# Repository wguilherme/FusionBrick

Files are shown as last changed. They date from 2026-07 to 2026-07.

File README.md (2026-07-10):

<div align="center">

🌐 **Português** | [English](README.en.md)

# FusionBrick

**Sistema de design modular open-source para makers, engenheiros e entusiastas.**





</div>

---

FusionBrick é um sistema de componentes modulares paramétricos para impressão 3D. Qualquer componente conecta em qualquer outro — em qualquer face, em qualquer direção — via press-fit, sem ferramentas.

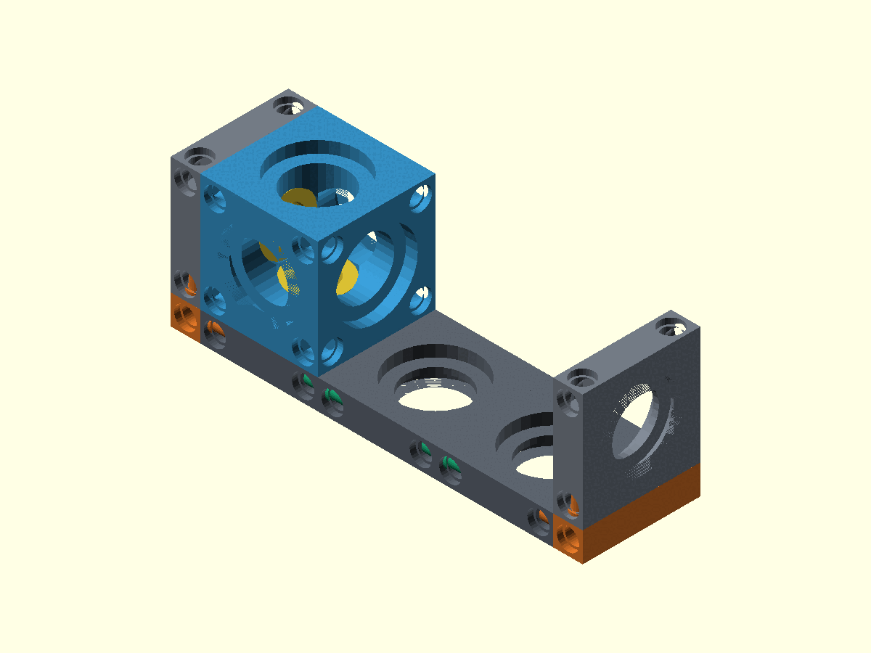
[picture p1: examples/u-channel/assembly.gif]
Montagem em U — 3 PLATEs unidas por BRIDGEs, paredes travadas por CORNERs e ATOM conectado por LINKs


---

## Componentes

| Componente | Preview | Função | Fonte |
| --- | :---: | --- | --- |
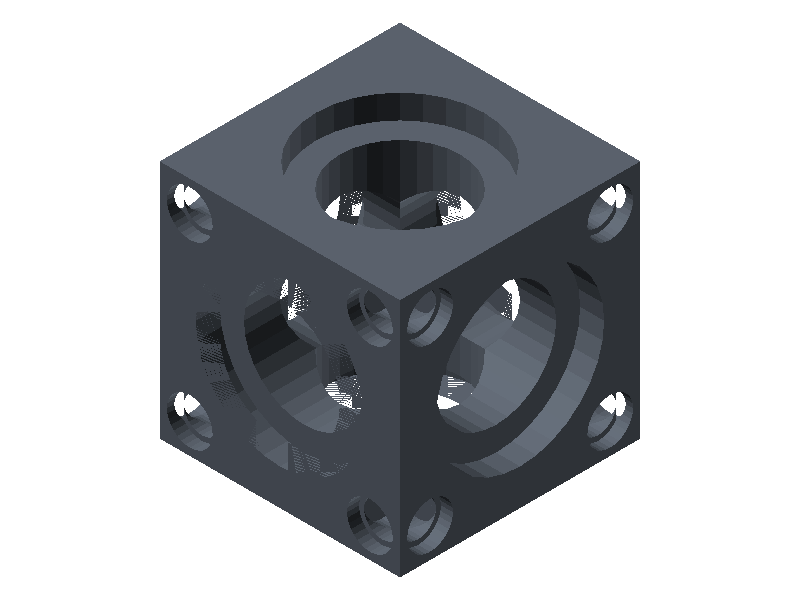
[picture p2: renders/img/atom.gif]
ATOM
| **ATOM** |  | Unidade cúbica. Furos passantes em 6 faces. | `impl/openscad/atom.scad` |
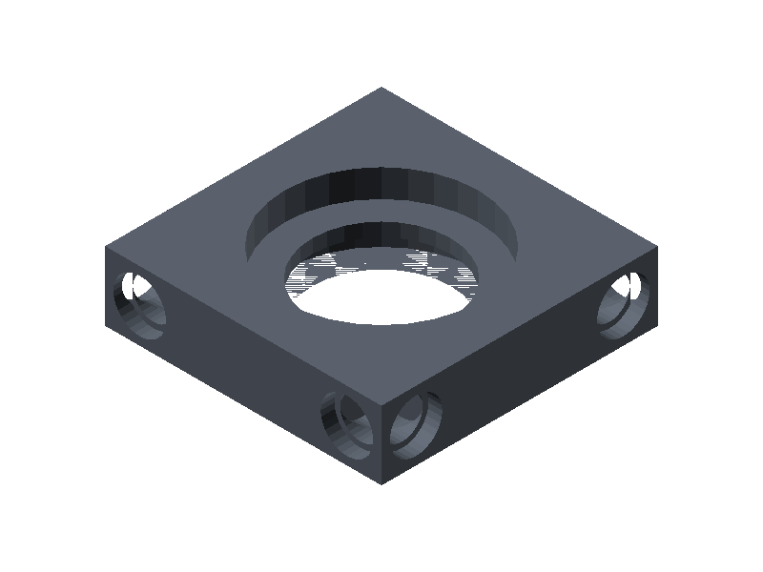
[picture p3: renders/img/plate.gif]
PLATE
| **PLATE** |  | Superfície plana. Furos alinhados ao ATOM. | `impl/openscad/plate.scad` |
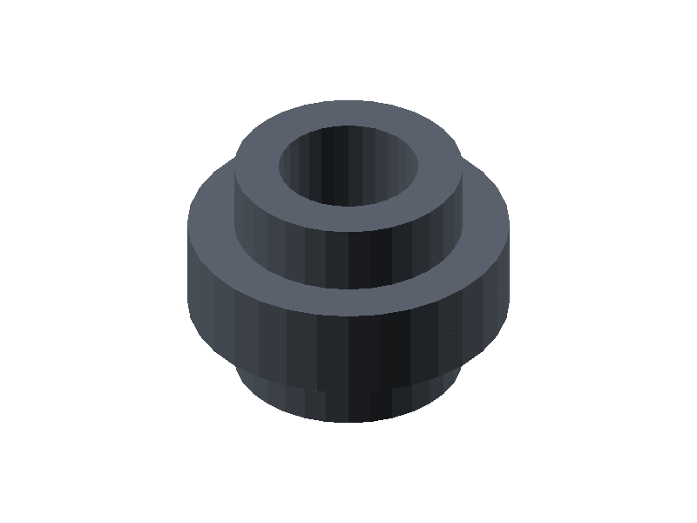
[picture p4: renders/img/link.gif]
LINK
| **LINK** |  | Conector universal entre quaisquer dois furos. | `impl/openscad/link.scad` |
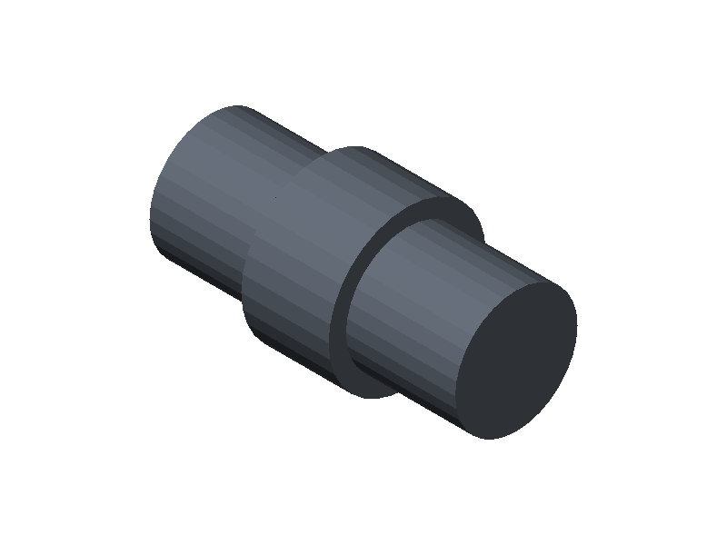
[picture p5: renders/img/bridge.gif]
BRIDGE
| **BRIDGE** |  | Dowel de junção coplanar invisível (PLATE↔PLATE, PLATE↔ATOM). | `impl/openscad/bridge.scad` |
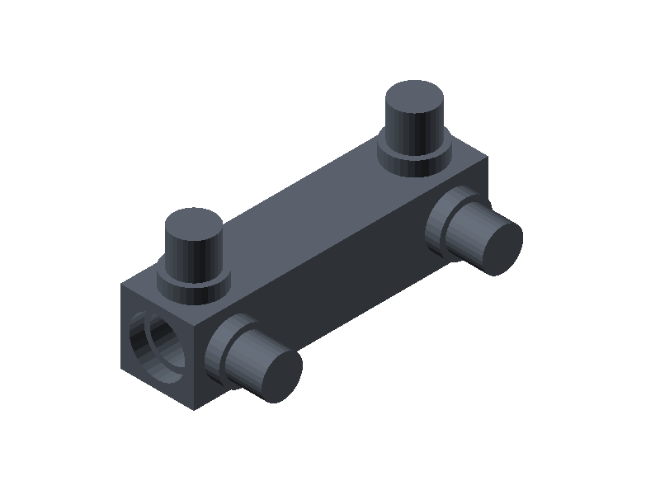
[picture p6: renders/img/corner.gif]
CORNER
| **CORNER** |  | Viga de canto. Une duas PLATEs a 90° via furos de borda. | `impl/openscad/corner.scad` |
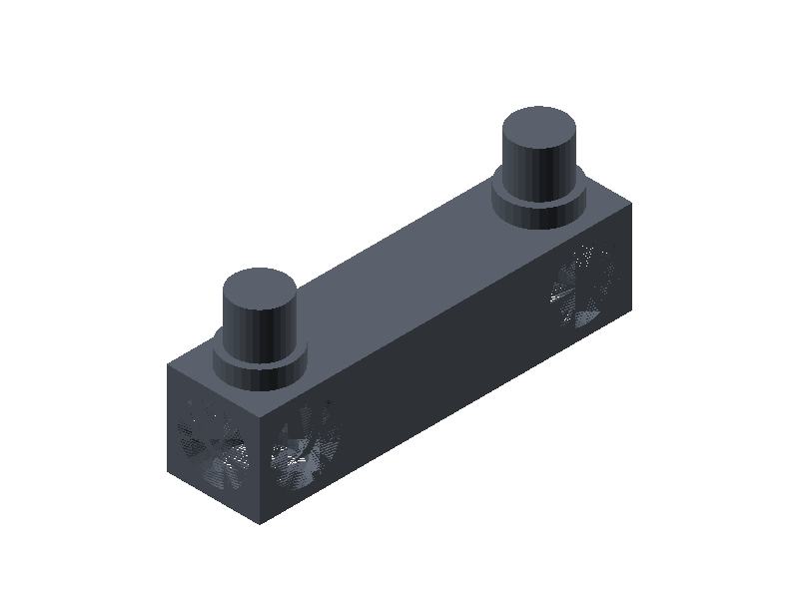
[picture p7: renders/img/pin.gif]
PIN
| **PIN** |  | Viga conectora configurável: pino, furo ou nada em cada face. Com presets. | `impl/openscad/pin.scad` |
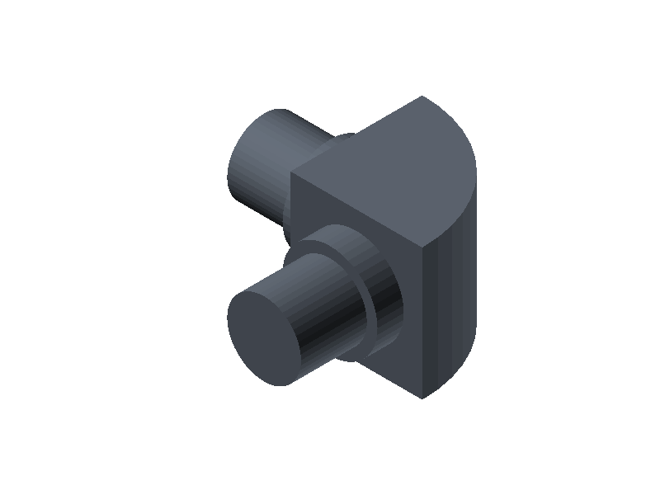
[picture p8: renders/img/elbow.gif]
ELBOW
| **ELBOW** |  | Curva 90° com canto externo arredondado. Fio vira a esquina por dentro. | `impl/openscad/elbow.scad` |
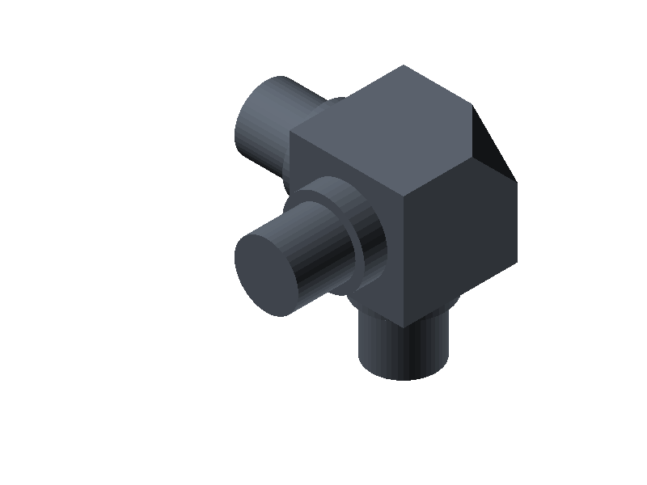
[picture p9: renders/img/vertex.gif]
VERTEX
| **VERTEX** |  | Quina 3-vias com ponta arredondada. Une base + 2 paredes num vértice. | `impl/openscad/vertex.scad` |

---

## Parâmetros Globais

Todos os parâmetros abaixo devem ser iguais entre os componentes para garantir compatibilidade.

```
cell_size     = 20mm   // unidade base da grade
hole_d        = 10mm   // diâmetro do furo
relief_depth  = 2mm    // profundidade do rebaixo
relief_margin = 2mm    // margem do rebaixo
tolerance     = 0.2mm  // tolerância de impressão (ajuste por impressora)
canal_d       = 6mm    // canal para fios em todo conector (0 = fechado)
```

Premissas do sistema: [spec/design-system.md](spec/design-system.md) · Lei do Grid e junções: [spec/rules.md](spec/rules.md).

---

## Início Rápido

**Requisitos:** OpenSCAD 2021+, impressora FDM, PLA ou PETG.

### 1. Instalar OpenSCAD

Via [download direto](https://openscad.org/downloads.html) ou via asdf:

```bash
asdf plugin add openscad https://github.com/gabrielelana/asdf-openscad
asdf install  # lê a versão de .tool-versions (2021.01)
```

### 2. Clonar e abrir

```bash
git clone https://github.com/wguilherme/FusionBrick.git
cd FusionBrick
open impl/openscad/atom.scad
```

Dentro do OpenSCAD: ajuste os parâmetros no painel lateral (ex: `atom_size`, `hole_d`, `border_radius`) → `F6` para renderizar → `File → Export → Export as STL`.

### 3. Gerar previews e STLs via Make

```bash
make preview            # renders/img/*.png — imagem isométrica de cada componente
make preview-animated   # renders/img/*.gif — giro 360° de cada componente
make build              # renders/stl/*.stl — STL pronto para fatiar
make assembly           # examples/*/assembly*.png — montagens isométricas (normal + explodida)
make assembly-animated  # examples/*/assembly.gif — giro 360° com explode/recolhe em loop
```

Para sobrescrever a cor dos componentes no preview:

```bash
make preview PART_COLOR="[0.8, 0.2, 0.1]"  # valores 0.0–1.0 (RGB)
```

Velocidade/suavidade dos GIFs animados:

```bash
make preview-animated ANIM_DELAY=10   # delay entre frames em 1/100s (padrão: 15)
make preview-animated ANIM_FRAMES=72  # frames por volta — mais suave (padrão: 36)

make assembly-animated ASM_ANIM_DELAY=10    # delay entre frames (padrão: 5)
make assembly-animated ASM_ANIM_FRAMES=96   # frames no loop completo (padrão: 72)
make assembly-animated ASM_ANIM_EXPLODE=20  # afastamento máximo em mm (padrão: 12)
make assembly-animated ASM_ANIM_SPIN=360    # habilita o giro completo (padrão: 0 — câmera isométrica fixa)
make assembly-animated ASM_ANIM_SPEED=2     # 2x mais rápido (padrão: 1; 0.5 = metade da velocidade)
```

Por padrão a câmera fica travada no ângulo isométrico (45°/54.7°) e a animação só abre/recolhe a montagem.

---

## Estrutura

```text
FusionBrick/
├── spec/                   ← especificação independente de ferramenta
│   ├── design-system.md    ← premissas do sistema
│   ├── params.md           ← parâmetros globais
│   ├── rules.md            ← Lei do Grid, interfaces, junções
│   └── parts/              ← spec de cada peça
├── impl/
│   ├── openscad/           ← implementação OpenSCAD ✅
│   ├── fusion360/          ← planejado
│   └── manual/             ← planejado
├── renders/
│   ├── img/                ← previews PNG
│   └── stl/                ← STLs exportados
└── examples/               ← montagens de exemplo (make assembly)
```

---

## Roadmap

### v0.1.0 — Fundação ✅

- [x] ATOM, PLATE, LINK
- [x] Implementação OpenSCAD
- [x] Especificação do sistema

### v0.2.0 — Junções & Interface de Borda ✅

- [x] Interface de borda: furos Ø3 nas extremidades de PLATEs e ATOMs, com rebaixo para colar
- [x] BRIDGE — dowel de junção coplanar invisível com colar central
- [x] CORNER — viga de canto 90° com canal para fio; dois CORNERs formam "L" flush
- [x] PIN — viga conectora configurável (pino/furo/nada por face) com presets
- [x] ELBOW — curva 90° arredondada; VERTEX — quina 3-vias com ponta arredondada
- [x] Canal para circuito elétrico por padrão em todo conector
- [x] Lei do Grid formalizada (`spec/design-system.md`, `spec/rules.md`)
- [x] `make assembly` — montagens isométricas com teste de colisão

### v0.3.0 — Paramétrico

- [ ] Seleção de padrão de furos (bordas, cantos, todos)
- [ ] Suporte multi-escala (10mm, 20mm, 30mm)
- [ ] Upload MakerWorld PMM

### v0.4.0+ — Futuro

- [ ] Canais para condução elétrica
- [ ] Conectores magnéticos
- [ ] Plugin Fusion 360

---

## Implementações

| Implementação | Status |
| --- | --- |
| OpenSCAD | ✅ Ativo |
| Fusion 360 | 🔜 Planejado |
| FreeCAD | 🔜 Planejado |
| MakerWorld PMM | 🔜 Planejado |

Quer contribuir? [Abra uma issue](https://github.com/wguilherme/FusionBrick/issues) ou envie um PR.

---

Feito com ❤️ para quem constrói  — [@wguilherme](https://github.com/wguilherme)

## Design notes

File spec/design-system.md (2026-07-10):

# Design System — Premissas

Princípios que governam o FusionBrick. Toda peça nova, mudança de parâmetro ou nova implementação deve respeitar todos eles. Se uma proposta viola qualquer premissa, a proposta muda — não a premissa.

## 1. O grid é sagrado

O passo do grid (`cell_size = 20mm`) nunca muda por causa de uma junção.

- Peças auxiliares (LINK, BRIDGE, CORNER e futuras) conectam furos existentes **sem inserir espaçamento**
- A espessura de PLATEs vive **fora** do volume do grid ([Lei do Grid](rules.md))
- Teste canônico: em qualquer montagem, um ATOM deve entrar em qualquer célula interior e alinhar com todos os furos vizinhos

## 2. Circuito elétrico passa por padrão

Toda peça e todo conector nascem com passagem para fio/jumper — fechar é opt-in, nunca default.

- Furos de face (`hole_d = 10mm`) são passantes
- Conectores têm canal axial: LINK `6mm`, CORNER `3mm` (mínimo: jumper Dupont, `2.5mm`)
- Quando a seção não comporta canal (ex: BRIDGE, pinos `Ø2.8`), a peça não pode bloquear as passagens existentes — a BRIDGE vive na borda justamente para deixar os furos de face livres
- `canal_d = 0` fecha o canal — escolha do usuário, nunca da spec

## 3. Compatibilidade é permanente

Tudo conecta com tudo, sempre — inclusive com peças impressas antes.

- Parâmetros globais ([params.md](params.md)) idênticos em todas as peças; divergiu, quebrou
- Peça nova deve usar as interfaces existentes ([rules.md](rules.md)); interface nova só quando nenhuma existente resolve — e vira contrato do sistema, documentada em `spec/`
- Mudança de interface é mudança de sistema: propaga para todas as peças, specs, implementações e exemplos de uma vez
- Nada de pares exclusivos: se a peça A conecta na B, deve conectar em qualquer peça com a mesma interface

## 4. Interfaces não competem

Cada interface tem seu papel; junções não consomem o recurso das outras.

| Interface | Onde | Serve para |
| --- | --- | --- |
| Face (furo `Ø10` + rebaixo `Ø14×2`) | faces de ATOM e PLATE | LINK, empilhamento, fixação de módulos |
| Borda (furo `Ø3` nas extremidades) | bordas de PLATE, faces laterais de ATOM | BRIDGE, CORNER — junções estruturais |

Consequência: montar uma junção nunca impede montar um módulo — ATOM assenta sobre qualquer junção.

## 5. Press-fit primeiro

- Sem ferramentas, sem parafusos, sem cola (cola é opção do usuário para montagem permanente)
- `tolerance = 0.2mm` subtraída sempre do conector, nunca da peça receptora — peças receptoras são nominais
- Ajuste fino por impressora acontece no conector (peça pequena, reimpressão barata)

## 6. Spec-first

- `spec/` é o contrato; `impl/` implementa. Divergência entre os dois é bug na implementação — ou proposta de mudança que deve começar pela spec
- Toda implementação (OpenSCAD, Fusion 360, …) que respeite a spec produz peças intercompatíveis

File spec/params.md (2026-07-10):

# Parâmetros Globais

Valores que devem ser idênticos em todas as peças. Se divergirem, os furos não alinham.

| Parâmetro | Valor | Descrição |
| --- | --- | --- |
| `cell_size` / `atom_size` | `20mm` | Unidade base do grid |
| `hole_d` | `10mm` | Diâmetro do furo passante |
| `relief_depth` | `2mm` | Profundidade do rebaixo |
| `relief_margin` | `2mm` | Margem do rebaixo → `relief_d = hole_d + relief_margin×2 = 14mm` |
| `tolerance` | `0.2mm` | Subtraída de pinos/flanges para press-fit |
| `canal_d` | `6mm` | Canal axial para fios em todo conector (0 = fechado) |
| `thickness` | `5mm` | Espessura padrão da PLATE — mínimo `(relief_depth×2)+1` |
| `pin_depth` | `3mm` | Profundidade do pino — caso mais restrito: PLATE (`thickness−relief_depth`) |
| `edge_hole_d` | `3mm` | Furo de borda de PLATE/ATOM (0 = desativado) |
| `edge_hole_depth` | `4mm` | Profundidade do furo de borda |
| `edge_inset` | `2.5mm` | Furo de borda a esta distância das extremidades (= `thickness/2`) |
| `edge_collar_w` | `0.4mm` | Largura radial do rebaixo/colar (= 1 bico de 0.4; 0 = desativado) |
| `edge_collar_depth` | `1mm` | Profundidade do rebaixo / altura do colar |
| `border_radius` | `0` | Acabamento das arestas externas (VERTEX: padrão `2`) |
| `border_style` | `round` | Estilo do acabamento: `round` (raio) ou `chamfer` (chanfro 45°) |
| `$fn` | `32` | Segmentos de cilindro |

## Derivados

```text
relief_d  = hole_d + relief_margin*2      = 14mm
pin_d     = hole_d - tolerance            = 9.8mm
flange_d  = relief_d - tolerance          = 13.8mm
```

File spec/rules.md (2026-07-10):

# Regras do Sistema

Regras de compatibilidade que toda peça e toda junção devem respeitar.

## Lei do Grid

> **O volume do grid é delimitado pelas faces internas das PLATEs. A espessura da PLATE vive sempre FORA do grid.**

Consequências:

1. **Superfície da base é plano do grid** — atoms assentam diretamente sobre ela; centro do atom fica a `cell_size/2` da superfície.
2. **Parede perpendicular** assenta com a borda inferior sobre a superfície da base e a face interna num plano do grid; a espessura projeta para fora.
3. **Primeiro furo de qualquer PLATE** fica a `cell_size/2` da borda → furos de parede ficam a `cell_size/2` acima da superfície da base → alinham com os furos laterais de um ATOM assentado na base.
4. Nenhuma junção pode alterar o passo do grid (`cell_size`). Peças de junção (LINK, BRIDGE, CORNER) conectam furos existentes sem inserir espaçamento.

## Junção coplanar (lado a lado)

Duas PLATEs encostadas borda a borda: furos de face ficam a `cell_size/2` de cada lado da junção → distância entre furos através da junção = `cell_size`. O grid se preserva automaticamente. Travamento **invisível** via dowels [BRIDGE](parts/bridge.md) na interface de borda (2 por junção) — faces 100% livres, ATOM assenta sobre a junção.

## Interface de borda

Segunda interface do sistema, nas bordas de PLATEs e faces laterais de ATOMs — complementa os furos de face sem competir com eles. Interface pura pino → furo, sem rebaixos:

- Furos de borda: `edge_hole_d = 3mm`, profundidade `4mm`, centrados na espessura
- 2 por célula, **nas extremidades**: a `edge_inset = 2.5mm` (= `thickness/2`) de cada limite da célula
- Distâncias: `15mm` dentro da célula; `5mm` através de junções — cada furo alinha com o centro da seção do CORNER (`5/2 = 2.5mm`)
- ATOM: 4 furos por face lateral (2 embaixo + 2 em cima), mesmas posições → PLATE ao lado de ATOM conecta direto
- **Rebaixo do colar**: boca de todo furo de borda ganha rebaixo `Ø3.8 × 1mm` (`edge_collar_w = 0.4` radial); todo pino tem colar `Ø3.6 × 1mm` na raiz → trava de profundidade (dowel divide 50/50, pino não afunda) e reforço da raiz
- Pinos receptores: `edge_hole_d - tolerance = 2.8mm`
- Usada por: [BRIDGE](parts/bridge.md) (dowel de junção coplanar), [CORNER](parts/corner.md) (junção 90° e L de corners), [PIN](parts/pin.md) (viga conectora configurável), [ELBOW](parts/elbow.md) (curva 90° arredondada), [VERTEX](parts/vertex.md) (quina 3-vias com ponta arredondada)

Vantagem estrutural: junções por borda deixam furos de face e rebaixos 100% livres — LINK e ATOM conectam em qualquer célula, inclusive nas do canto.

## Junção perpendicular (90°)

Base e parede se encontram borda-com-borda, deixando uma lacuna de `thickness × thickness` no canto externo. A viga [CORNER](parts/corner.md) preenche essa lacuna e pina nos furos de borda das duas PLATEs — nada protrui, interior 100% livre. Alternativa zero-peças: ATOM na célula do canto + 2 LINKs (custo: célula ocupada).

Verificação canônica — U (`|_|`) com base de `n` células e duas paredes: interior = exatamente `n` células livres; um ATOM entra em qualquer célula e conecta na base e nas paredes.

## Passagem elétrica

Todo conector (LINK, BRIDGE, CORNER) tem canal axial `canal_d = 6mm` por padrão em cada ponta de encaixe — fio/jumper atravessa qualquer junção. `canal_d = 0` fecha o canal (opt-out, nunca default).

## Furos laterais em PLATE

Impossíveis por construção: `hole_d (10mm) > thickness (5mm)`. Toda junção envolvendo PLATE usa os furos das faces (topo/base) — os rebaixos existem em ambas as faces exatamente por isso.

## Tolerância

`tolerance = 0.2mm` subtraída de todo pino e flange para press-fit. Ajuste por impressora: aumentar se apertar, diminuir se folgar.

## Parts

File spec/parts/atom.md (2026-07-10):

# ATOM

Unidade estrutural cúbica do sistema. Bloco base de construção.

## Geometria

- Forma: cubo `atom_size × atom_size × atom_size`
- Tamanho padrão: `20 × 20 × 20 mm`
- `border_radius` opcional para acabamento das arestas (padrão: `0`) + `border_style`: `round` (raio) ou `chamfer` (chanfro 45°)

## Furos

- **6 faces** — furo passante central em cada face
- Diâmetro do furo: `hole_d = 10mm`
- Rebaixo em ambas as extremidades de cada furo:
  - Diâmetro: `relief_d = hole_d + (relief_margin × 2) = 14mm`
  - Profundidade: `relief_depth = 2mm`

O rebaixo aloja o flange do LINK, garantindo face plana após montagem.

## Furos de borda

Interface lateral compatível com a PLATE — uma PLATE encostada ao lado de um ATOM conecta via dowels do [BRIDGE](bridge.md), respeitando o grid.

- **4 furos por face lateral** (por célula): 2 embaixo + 2 em cima
- Diâmetro `edge_hole_d = 3mm`, profundidade `edge_hole_depth = 4mm`
- Posição: a `edge_inset = 2.5mm` das extremidades (largura e altura) — mesmas posições dos furos de borda da PLATE
- Rebaixo do colar: boca de cada furo com `Ø3.8 × 1mm` — assenta o colar do pino (trava de profundidade)
- Aplicados apenas nas 4 faces laterais externas do grid (`edge_hole_d = 0` desativa)

## Instâncias múltiplas

Suporta grade `qty_x × qty_y × qty_z` de ATOMs unidos, com furos alinhados entre unidades adjacentes.

## Restrições

- `hole_d` deve ser menor que `atom_size / 2`
- `relief_d` deve caber dentro da face: `relief_d < atom_size`
- `border_radius` máximo: `atom_size / 2 - ε`

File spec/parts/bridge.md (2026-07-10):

# BRIDGE

Dowel de junção coplanar. Pino duplo que atravessa a junção entre duas PLATEs (ou PLATE↔ATOM) encostadas borda a borda, entrando nos furos de borda de cada lado. Só pino → furo: nada acima ou abaixo da superfície, nenhum furo de face consumido.

## Geometria

```text
Vista de cima (junção vertical):

  PLATE A      │      PLATE B
       ━━━━━━━━┿━━━━━━━━      ← dowel Ø2.8 (metade em cada furo)
               │ ← peças ENCOSTADAS — gap zero
```

- **Dowel**: `edge_hole_d - tolerance = Ø2.8mm`, comprimento `7mm` (`edge_hole_depth - 0.5 = 3.5mm` em cada peça — não bate no fundo)
- **Colar central**: `Ø3.6 × 2mm` (1mm para cada lado da junção) — assenta nos rebaixos das duas bocas, garantindo divisão 50/50 da profundidade
- **Uso**: 2 dowels por junção — um em cada furo de borda do par de células (a `2.5mm` de cada extremidade) — para travar rotação

## Papel estrutural

- Cisalhamento e alinhamento entre as peças
- 2 dowels afastados = anti-rotação

## Uso

- Junção 100% invisível: faces de cima e de baixo lisas, ATOM assenta sobre a junção
- Sem canal de fio (seção Ø2.8 não comporta) — fios atravessam pelos furos de face, que ficam livres
- Serve PLATE↔PLATE e PLATE↔ATOM (o ATOM tem os mesmos furos de borda)

## Restrições

- Requer furos de borda nas duas peças (padrão em PLATE e ATOM)
- Não altera o passo do grid: peças encostadas, gap zero

## Histórico

- v1 (dogbone com flanges nos rebaixos de face): descartada — consumia furos de face e protruía `2mm`
- v2 (dowels + alma enterrada em rebaixo de borda): descartada — rebaixo removido em favor de interface pino→furo pura

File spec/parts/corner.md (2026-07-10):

# CORNER

Viga de canto. Preenche a lacuna `wall_thickness × plate_thickness` que sobra quando duas PLATEs se encontram a 90° borda-com-borda. Conecta via **furos de borda** — furos de face e rebaixos ficam 100% livres para LINKs e ATOMs.

## Geometria

```text
      │ │ parede
      │ │
      └┬┘ ← borda inferior da parede
   ┌─┐ ▲ pinos ↑ furos de borda da parede
   │▓├►┌──────────── base
   └─┘ └──────────── pinos → furos de borda da base
    ↑ viga preenche a lacuna (thickness × thickness)
```

- **Corpo**: prisma `wall_thickness × plate_thickness × (cells × cell_size)`
- **Pinos** em 2 faces perpendiculares: `edge_pin_d = edge_hole_d - tolerance = 2.8mm`, comprimento `3.5mm` (< profundidade do furo de borda, para não bater no fundo), com colar `Ø3.6 × 1mm` na raiz (trava de profundidade + reforço)
- **Posições**: 2 pinos por célula, **nas extremidades** — a `edge_inset = 2.5mm` de cada limite da célula (mesmas posições dos furos de borda de PLATE/ATOM)
- **Canal**: `canal_d = 3mm` axial ao longo da viga — passa jumper Dupont e serve de soquete para o pino de outro CORNER (0 = fechado); bocas com rebaixo `Ø3.8 × 1mm` para o colar do pino
- **Acabamento**: `border_radius` (padrão `0`) + `border_style` `round`/`chamfer` nas arestas da viga

## Encaixe em L (CORNER ↔ CORNER)

O pino da ponta fica a `edge_inset = 2.5mm` do fim da viga = **centro da seção** (`5/2`). Duas vigas perpendiculares formam um "L" flush:

- Viga B em pé sobre a face de pinos da viga A, na região da ponta
- O pino da ponta de A entra no **canal axial** (Ø3) de B — press-fit igual furo de borda
- Faces externas alinham exatamente: sem sobra, sem beirada

## Lei do Grid — preservada

- Face interna da parede num plano do grid; borda inferior no plano da superfície da base
- Furo da parede a `cell_size/2` da superfície → ATOM assentado na base alinha
- **Nada protrui**: faces externas da viga ficam flush com a base (embaixo) e a parede (fora)
- Furos de face intocados → LINK/ATOM conectam em qualquer furo, inclusive nas células do canto

## Alternativas

- **ATOM como corner** (zero peças novas): ATOM na célula do canto + 2 LINKs — custo: célula ocupada
- Bracket externo em L: descartado — protruía sob a base e consumia furos de face

## Restrições

- Requer PLATE com furos de borda (`edge_hole_d = 3mm`, padrão)
- `cells` da viga deve corresponder ao comprimento da junção
- Pinos Ø2.8 em FDM são finos — a resistência vem da quantidade (2 por célula) e do corpo da viga preenchendo a lacuna

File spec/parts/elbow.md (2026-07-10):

# ELBOW

Curva 90° da interface de borda. Liga duas vigas ([CORNER](corner.md)/[PIN](pin.md)) ou furos de borda perpendiculares com o canto externo **arredondado** — alternativa estética ao encaixe em L de quinas vivas.

## Geometria

```text
     ╭──────┐
    ╱       │ ← porta B (aponta -X)
   │   ◜    │
   │  ╱     │
   └──┴─────┘
      ↑ porta A (aponta -Y)
```

- **Corpo**: varredura de 90° da seção `sec × sec` (padrão `5×5`), raio externo = `sec` — ocupa exatamente o volume `5×5×5` da quina
- **Portas** (×2, perpendiculares): `pin` (colar Ø3.6×1 + haste Ø2.8, total 3.5mm) ou `hole` (bore Ø3×4 + rebaixo Ø3.8×1), no centro da seção
- **Canal curvo**: com as duas portas em `hole`, um arco Ø3 liga os centros das portas por dentro — **fio vira a esquina dentro da peça**
- **Acabamento**: `border_radius` (padrão `0`) + `border_style` `round`/`chamfer` nas 4 arestas que acompanham a curva; faces das portas ficam planas (flush)

## Compatibilidade

- Pino entra no canal axial de CORNER/PIN e em qualquer furo de borda (PLATE, ATOM)
- Furo recebe pino de CORNER/PIN/VERTEX e dowel de BRIDGE
- Não altera o passo do grid: substitui o volume da quina, faces planas flush com as vigas

## Restrições

- Ângulo fixo 90° — sistema é ortogonal (Lei do Grid)
- Raio externo acompanha `sec`; seções diferentes de `5` exigem vigas de mesma seção

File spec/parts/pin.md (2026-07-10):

# PIN

Viga conectora universal da interface de borda. Parente do [CORNER](corner.md), mas totalmente configurável: cada grupo de faces (topo, base, laterais, pontas) pode ter **pino**, **furo** ou nada.

## Geometria

- **Corpo**: prisma `sec_w × sec_h × (cells × cell_size)` — padrão `5 × 5 × 20mm` (seção = espessura da PLATE)
- **Posições**: nas extremidades de cada célula, a `edge_inset = 2.5mm` dos limites — mesmas posições de toda a interface de borda
- **Pino**: colar `Ø3.6 × 1mm` na raiz + haste `Ø2.8`, total `3.5mm`
- **Furo**: bore `Ø3 × 4mm` + rebaixo do colar `Ø3.8 × 1mm` na boca
- Pontas (±Y): 1 feature axial centrado na seção
- **Acabamento**: `border_radius` (padrão `0`) + `border_style` `round`/`chamfer` nas arestas da viga
- Furos opostos se encontram (4+4 > 5) e viram furo passante — esperado

## Configuração

| Grupo | Parâmetro | Opções |
| --- | --- | --- |
| Topo (+Z) | `face_top` | `pin` / `hole` / `none` |
| Base (−Z) | `face_bottom` | `pin` / `hole` / `none` |
| Laterais (±X) | `face_sides` | `pin` / `hole` / `none` |
| Pontas (±Y) | `face_ends` | `pin` / `hole` / `none` |

## Presets

| `preset` | Topo | Base | Laterais | Pontas | Uso |
| --- | --- | --- | --- | --- | --- |
| `full_pins_hole_bottom` | pino | furo | pino | pino | espalhar conexões a partir de uma base |
| `full_holes` | furo | furo | furo | furo | hub fêmea universal — recebe pinos de qualquer peça |
| `custom` (padrão) | `face_*` | `face_*` | `face_*` | `face_*` | qualquer combinação |

## Compatibilidade

- Pinos entram em qualquer furo de borda do sistema (PLATE, ATOM, CORNER via canal, outro PIN)
- Furos recebem pinos de CORNER, dowels de BRIDGE e pinos de outro PIN
- Encaixe em L igual ao CORNER: feature da ponta fica no centro da seção

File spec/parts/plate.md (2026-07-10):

# PLATE

Superfície plana modular. Grid de furos alinhado ao ATOM.

## Geometria

- Forma: placa plana `(cell_size × qty_x) × (cell_size × qty_y) × thickness`
- `qty_x` e `qty_y`: padrão `1` (unidade mínima — 1×1 = 20×20mm)
- `cell_size` deve ser igual ao `atom_size` do ATOM para garantir alinhamento
- `thickness` mínima: `(relief_depth × 2) + 1mm` → padrão mínimo: `5mm`
- `border_radius` opcional (padrão: `0`) + `border_style`: `round` (raio) ou `chamfer` (chanfro 45°)

## Furos

- Grid `qty_x × qty_y` de furos, um por célula, centralizado em cada célula
- Diâmetro: `hole_d = 10mm`
- Rebaixo em **ambas as faces**:
  - Diâmetro: `relief_d = 14mm`
  - Profundidade: `safe_relief = min(relief_depth, thickness/2 - 0.5)`

## Furos de borda

Interface lateral nas 4 bordas — recebe os pinos do [CORNER](corner.md) e os dowels do [BRIDGE](bridge.md), sem consumir furos de face nem rebaixos. Só pino → furo, sem rebaixos laterais.

- Diâmetro: `edge_hole_d = 3mm` (máximo seguro: `thickness - 2mm` de parede; `0` desativa)
- Profundidade: `edge_hole_depth = 4mm`
- Posição: centrados na espessura; 2 por célula, **nas extremidades** — a `edge_inset = 2.5mm` (= `thickness/2`) de cada limite da célula
- Distâncias resultantes: `15mm` entre os furos da mesma célula; `5mm` entre furos através de junções — cada furo alinha com o centro da seção do CORNER
- Rebaixo do colar: boca de cada furo com `Ø3.8 × 1mm` — assenta o colar do pino (trava de profundidade)
- Nota: furos perpendiculares próximos ao mesmo canto se cruzam internamente (profundidade 4 > inset 2.5) — esperado; o pino mantém agarre na maior parte da circunferência

## Compatibilidade

Ao encostar duas PLATEs lado a lado, a distância entre furos na junção é `cell_size/2 + cell_size/2 = cell_size` — mesma distância do grid interno. Furos coincidem matematicamente com qualquer peça do sistema.

- Junção coplanar: travar com [BRIDGE](bridge.md)
- Junção perpendicular (90°): travar com [CORNER](corner.md)
- Regras completas: [Lei do Grid](../rules.md)

## Restrições

- `thickness < relief_depth × 2` invalida a peça — implementação deve aplicar `safe_relief` automaticamente
- `border_radius` máximo: `min(thickness/2, cell_size/2) - ε`

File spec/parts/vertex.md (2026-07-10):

# VERTEX

Quina 3-vias com ponta arredondada. Une as 3 peças que convergem num vértice — base + 2 paredes de uma caixa, ou 3 vigas [CORNER](corner.md)/[PIN](pin.md) nas arestas.

## Geometria

- **Corpo**: cubo `sec × sec × sec` (padrão `5×5×5`)
- **Ponta externa** (`+X,+Y,+Z`): acabada com `border_radius = 2mm` (padrão do sistema) — `border_style = "round"` (esfera) ou `"chamfer"` (facetas retas 45°). As arestas externas ficam vivas — continuam flush com a seção quadrada das vigas
- **3 faces internas** (`X=0`, `Y=0`, `Z=0`): cada uma com `pin` / `hole` / `none` no **centro da face** (`sec/2 = 2.5mm`)
  - Pino: colar Ø3.6×1 + haste Ø2.8, total 3.5mm
  - Furo: bore Ø3×4 + rebaixo Ø3.8×1

## Alinhamento

O centro da face (`2.5, 2.5`) alinha simultaneamente com:

- o canal axial de uma viga CORNER/PIN encostada na face
- o furo de borda no canto de uma PLATE (que fica a `2.5mm` das duas bordas)

→ o VERTEX pina direto em vigas ou em cantos de PLATEs, sem adaptador.

## Passagem de fio

Com 2+ faces em `hole`, os bores (4mm > sec/2) se encontram no centro do cubo — **fio vira a esquina por dentro** (junção em T/L interna).

## Restrições

- `border_radius` máximo: `sec/2 - ε`
- Não altera o passo do grid: ocupa o volume do vértice que as 3 peças deixam livre

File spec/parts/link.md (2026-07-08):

# LINK

Conector universal. Une quaisquer dois furos do sistema — ATOM↔ATOM, PLATE↔PLATE, ATOM↔PLATE.

## Geometria

Peça simétrica em dois sentidos, composta por dois semi-links espelhados:

```text
[flange] [pin →] [spacer?] [← pin] [flange]
```

- **Flange**: assenta no rebaixo (`relief_d`), mantém face plana
  - Diâmetro: `flange_d = relief_d - tolerance`
  - Altura: `relief_depth`
- **Pin**: entra no furo passante
  - Diâmetro: `pin_d = hole_d - tolerance`
  - Profundidade: `pin_depth` (varia por contexto — ver abaixo)
- **Spacer** (opcional): haste entre os dois flanges para conectar peças com gap
  - Comprimento: `spacer` (padrão: `0`)
- **Canal** (padrão aberto): furo axial para passagem de fio/cabo
  - Diâmetro: `canal_d` (padrão: `6mm` — passagem confortável para fios/cabos)
  - Zerar (`canal_d = 0`) fecha o canal; aumentar para cabos mais grossos

## Tolerância

`tolerance = 0.2mm` subtraída de `flange_d` e `pin_d` para press-fit.  
Aumentar se apertar; diminuir se folgar.

## pin_depth por contexto

| Contexto | pin_depth recomendado |
| --- | --- |
| ATOM ↔ ATOM | `3mm` |
| ATOM ↔ PLATE | `3mm` |
| PLATE ↔ PLATE (empilhadas) | `3mm` |

Junções coplanares e a 90° não usam LINK — ver [BRIDGE](bridge.md) e [CORNER](corner.md) (interface de borda).

## Comprimento total

`total_length = (relief_depth + pin_depth) × 2 + spacer`

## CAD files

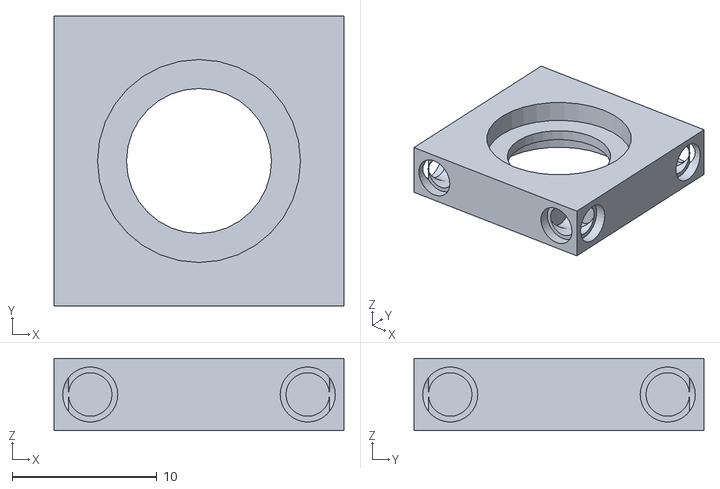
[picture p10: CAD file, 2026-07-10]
renders/stl/plate.stl
20.0 x 20.0 x 5.00

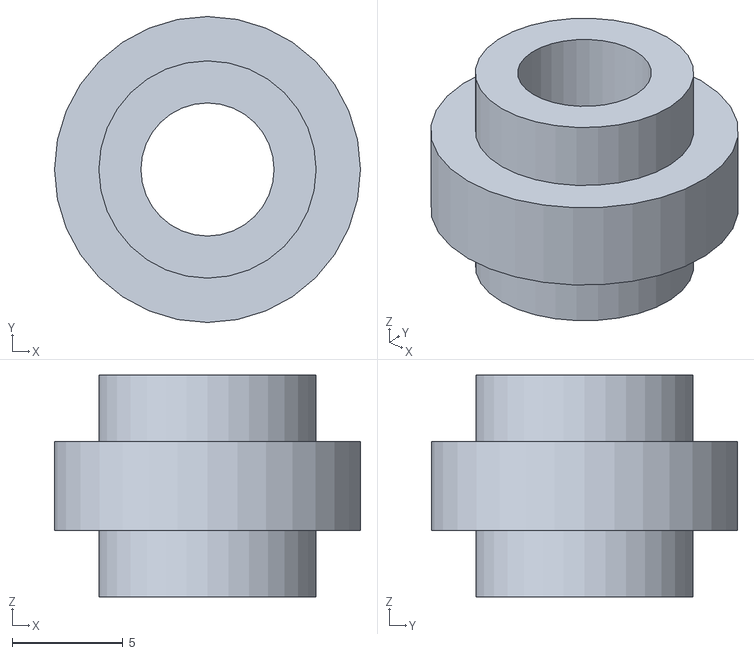
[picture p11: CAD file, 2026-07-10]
renders/stl/link.stl
13.8 x 13.8 x 10.0

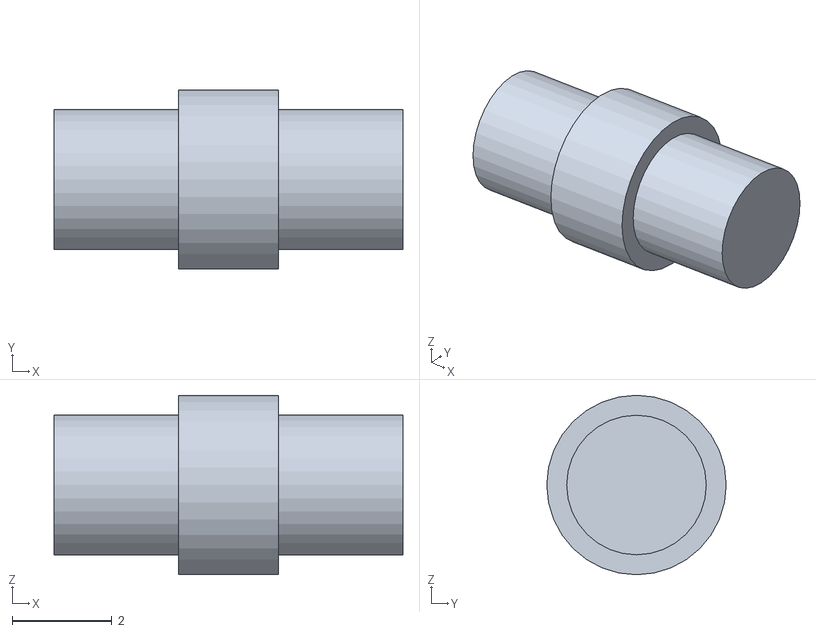
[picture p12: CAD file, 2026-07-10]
renders/stl/bridge.stl
7.00 x 3.60 x 3.60

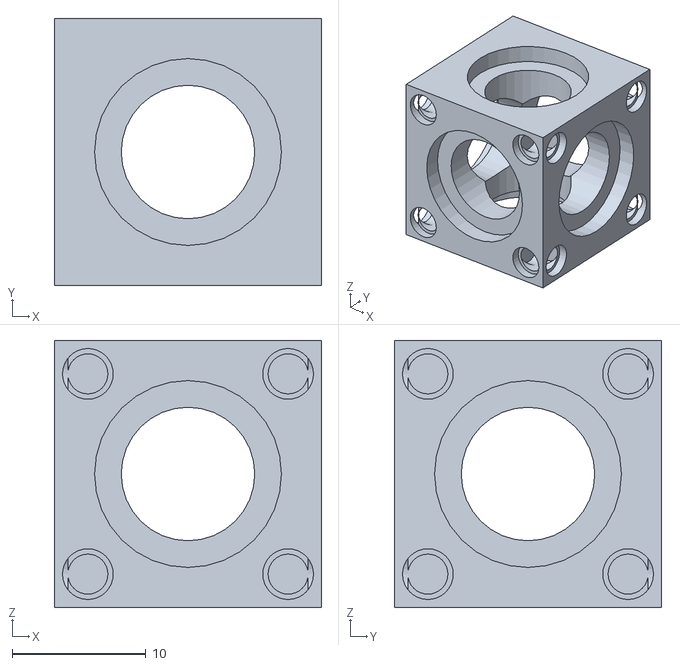
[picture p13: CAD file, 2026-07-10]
renders/stl/atom.stl
20.0 x 20.0 x 20.0

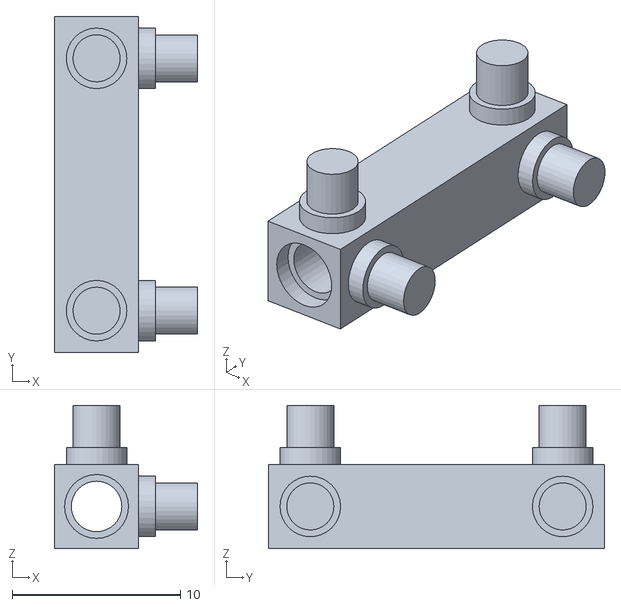
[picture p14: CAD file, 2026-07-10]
renders/stl/corner.stl
8.50 x 20.0 x 8.50

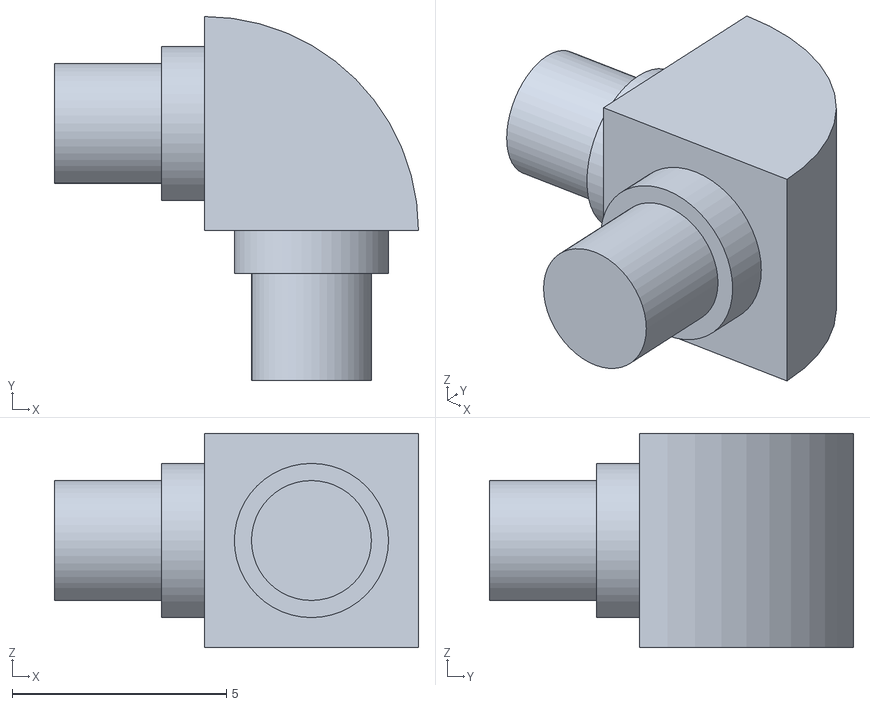
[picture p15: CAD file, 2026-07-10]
renders/stl/elbow.stl
8.50 x 8.50 x 5.00

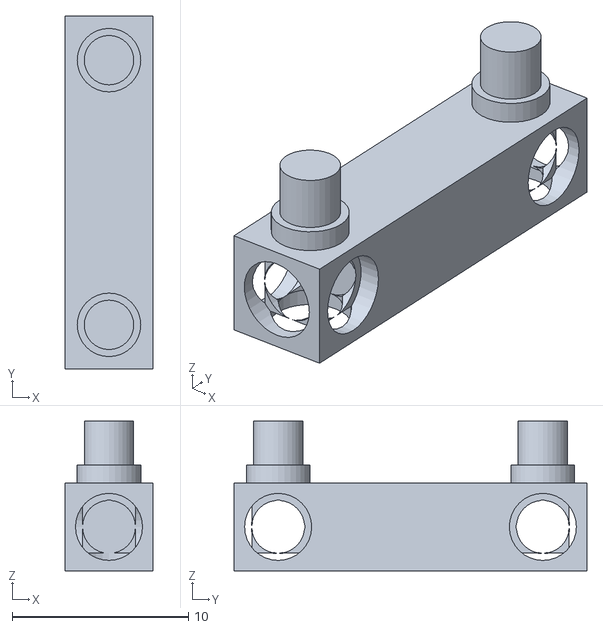
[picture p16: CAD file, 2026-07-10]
renders/stl/pin.stl
5.00 x 20.0 x 8.50

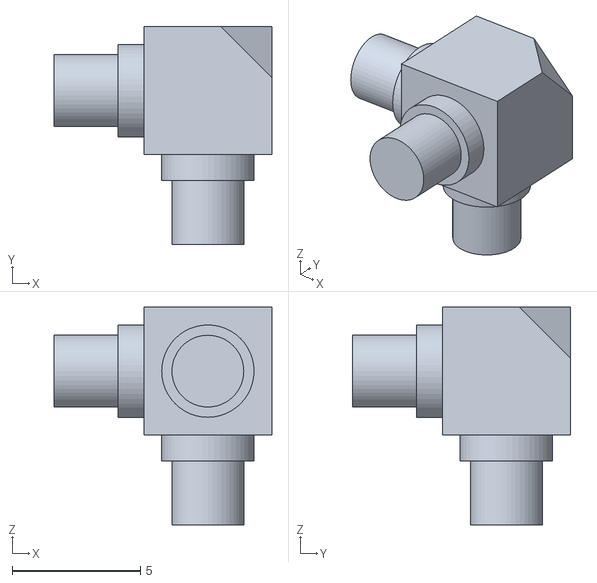
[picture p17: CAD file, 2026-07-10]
renders/stl/vertex.stl
8.50 x 8.50 x 8.50

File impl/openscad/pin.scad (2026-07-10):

// ============================================================
// PIN — Design System 3D Modular
// ============================================================
// Viga conectora universal da interface de borda. Parente do
// CORNER, mas totalmente configurável: cada grupo de faces
// (topo, base, laterais, pontas) pode ter PINO, FURO ou nada.
//
// Seção sec_w × sec_h (padrão 5×5 = espessura da PLATE),
// comprimento em células do grid. Pinos e furos ficam nas
// extremidades de cada célula (edge_inset), como todo o sistema.
//
//        pinos ↑ ↑
//       ┌─┴───────┴─┐
//    →  │           │  ←   furos/pinos nas laterais e pontas
//       └─┬───────┬─┘
//        furos ↓ ↓
//
// Presets (parâmetro `preset`):
//   custom               → usa face_top/face_bottom/face_sides/face_ends
//   full_pins_hole_bottom→ pinos no topo, laterais e pontas; furos na base
//   full_holes           → furos em todas as faces
//
// Furos: bore Ø3 × 4mm + rebaixo do colar na boca (Ø3.8 × 1mm)
// Pinos: colar Ø3.6 × 1mm na raiz + haste Ø2.8 (total 3.5mm)
// Furos opostos se encontram (profundidade 4+4 > seção 5) e
// viram furo passante — esperado.
// ============================================================

/* [Preset] */

// Preset de configuração (custom usa os parâmetros de faces abaixo)
preset = "custom"; // [custom, full_pins_hole_bottom, full_holes]

/* [Faces — usados quando preset = custom] */

// Face de cima (+Z)
face_top = "pin"; // [pin, hole, none]

// Face de baixo (-Z)
face_bottom = "hole"; // [pin, hole, none]

// Faces laterais (±X)
face_sides = "hole"; // [pin, hole, none]

// Pontas (±Y, axiais)
face_ends = "hole"; // [pin, hole, none]

/* [Tamanho] */

// Comprimento da viga em células
cells = 1; // [1:1:20]

// Passo do grid (= cell_size do sistema)
cell_size = 20; // [5:1:100]

// Largura da seção, eixo X (= thickness da PLATE)
sec_w = 5; // [3:0.5:20]

// Altura da seção, eixo Z (= thickness da PLATE)
sec_h = 5; // [3:0.5:20]

/* [Interface de borda — manter igual à PLATE/ATOM] */

// Diâmetro do furo de borda (mm)
edge_hole_d = 3; // [1:0.1:5]

// Profundidade do furo de borda (mm)
edge_hole_depth = 4; // [1:0.5:10]

// Distância do centro do furo/pino até a extremidade da célula
edge_inset = 2.5; // [1:0.25:5]

// Comprimento total do pino (colar + haste)
edge_pin_len = 3.5; // [1:0.25:9]

// Largura radial do rebaixo/colar (0 = desativado)
edge_collar_w = 0.4; // [0:0.1:1]

// Profundidade do rebaixo / altura do colar (mm)
edge_collar_depth = 1; // [0.5:0.25:2]

/* [Bordas] */

// Raio de acabamento das arestas da viga (0 = arestas vivas)
border_radius = 0; // [0:0.1:2]

// Estilo do acabamento das arestas: round (raio) ou chamfer (chanfro 45°)
border_style = "round"; // [round, chamfer]

/* [Tolerância de impressão] */

// Folga de encaixe
tolerance = 0.2; // [0:0.05:0.5]

/* [Qualidade] */
$fn = 32;

// ============================================================
// CALCULADOS
// ============================================================

// Configuração efetiva de cada grupo de faces (preset > custom)
top_c    = preset == "full_holes" ? "hole" : preset == "full_pins_hole_bottom" ? "pin"  : face_top;
bottom_c = preset == "full_holes" ? "hole" : preset == "full_pins_hole_bottom" ? "hole" : face_bottom;
sides_c  = preset == "full_holes" ? "hole" : preset == "full_pins_hole_bottom" ? "pin"  : face_sides;
ends_c   = preset == "full_holes" ? "hole" : preset == "full_pins_hole_bottom" ? "pin"  : face_ends;

// Diâmetros efetivos
edge_pin_d = edge_hole_d - tolerance;
collar_d   = edge_hole_d + 2 * edge_collar_w - tolerance;
recess_d   = edge_hole_d + 2 * edge_collar_w;

// Comprimento total da viga
beam_length = cells * cell_size;

// Posições ao longo da viga — nas extremidades de cada célula
pin_positions = [
    for (c = [0 : cells - 1], s = [0, 1])
        c * cell_size + edge_inset + s * (cell_size - 2 * edge_inset)
];

// Raio seguro — limitado pela seção da viga
safe_radius = min(border_radius, sec_w / 2 - 0.01, sec_h / 2 - 0.01);

// ============================================================
// MÓDULOS
// ============================================================

// ------------------------------------------------------------
// Módulo: sólido de acabamento das arestas — esfera (round)
// ou octaedro (chamfer 45°), usado no minkowski
// ------------------------------------------------------------
module border_finish(r) {
    if (border_style == "chamfer")
        polyhedron(
            points = [[r,0,0],[-r,0,0],[0,r,0],[0,-r,0],[0,0,r],[0,0,-r]],
            faces  = [[4,2,0],[4,1,2],[4,3,1],[4,0,3],[5,0,2],[5,2,1],[5,1,3],[5,3,0]]
        );
    else
        sphere(r = r);
}

// ------------------------------------------------------------
// Módulo: corpo da viga com acabamento de aresta opcional
// ------------------------------------------------------------
module beam_body() {
    if (safe_radius <= 0) {
        translate([-sec_w / 2, 0, -sec_h / 2])
            cube([sec_w, beam_length, sec_h]);
    } else {
        minkowski() {
            translate([-sec_w / 2 + safe_radius, safe_radius, -sec_h / 2 + safe_radius])
                cube([sec_w - 2 * safe_radius,
                      beam_length - 2 * safe_radius,
                      sec_h - 2 * safe_radius]);
            border_finish(safe_radius);
        }
    }
}

// Pino com colar na raiz — orientado em +Z a partir da origem
module edge_pin() {
    if (edge_collar_w > 0)
        cylinder(d = collar_d, h = edge_collar_depth);
    cylinder(d = edge_pin_d, h = edge_pin_len);
}

// Furo com rebaixo do colar na boca — orientado em -Z (fura
// para dentro) a partir da origem na superfície
module edge_hole_cut() {
    eps = 0.01;
    rotate([180, 0, 0]) {
        cylinder(d = edge_hole_d, h = edge_hole_depth + eps);
        if (edge_collar_w > 0)
            cylinder(d = recess_d, h = edge_collar_depth + eps);
    }
}

// Aplica pino OU furo numa posição/orientação
// (rot orienta +Z do feature para fora da face)
module face_feature(cfg, pos, rot) {
    if (cfg == "pin")
        translate(pos) rotate(rot) edge_pin();
}
module face_feature_cut(cfg, pos, rot) {
    if (cfg == "hole")
        translate(pos) rotate(rot) edge_hole_cut();
}

// ------------------------------------------------------------
// Módulo: PIN completo — viga centrada em X/Z, y ∈ [0, length]
// ------------------------------------------------------------
module pin() {
    difference() {
        union() {
            // Corpo da viga
            beam_body();

            // Pinos
            for (y = pin_positions) {
                face_feature(top_c,    [0,  y,  sec_h / 2], [0, 0, 0]);
                face_feature(bottom_c, [0,  y, -sec_h / 2], [180, 0, 0]);
                face_feature(sides_c,  [ sec_w / 2, y, 0],  [0, 90, 0]);
                face_feature(sides_c,  [-sec_w / 2, y, 0],  [0, -90, 0]);
            }
            face_feature(ends_c, [0, 0, 0],           [90, 0, 0]);
            face_feature(ends_c, [0, beam_length, 0], [-90, 0, 0]);
        }

        // Furos
        for (y = pin_positions) {
            face_feature_cut(top_c,    [0,  y,  sec_h / 2], [0, 0, 0]);
            face_feature_cut(bottom_c, [0,  y, -sec_h / 2], [180, 0, 0]);
            face_feature_cut(sides_c,  [ sec_w / 2, y, 0],  [0, 90, 0]);
            face_feature_cut(sides_c,  [-sec_w / 2, y, 0],  [0, -90, 0]);
        }
        face_feature_cut(ends_c, [0, 0, 0],           [90, 0, 0]);
        face_feature_cut(ends_c, [0, beam_length, 0], [-90, 0, 0]);
    }
}

// ============================================================
// RENDER
// ============================================================
part_color = [0.35, 0.38, 0.42];
color(part_color) pin();

// ============================================================
// INFO — dimensões no console
// ============================================================
echo("=== PIN ===");
echo(str("Preset             : ", preset));
echo(str("Viga               : ", sec_w, " × ", sec_h, " × ", beam_length, "mm (", cells, " célula(s))"));
echo(str("Faces              : topo=", top_c, " base=", bottom_c, " laterais=", sides_c, " pontas=", ends_c));
echo(str("Pino               : Ø", edge_pin_d, "mm × ", edge_pin_len, "mm + colar Ø", collar_d, "mm × ", edge_collar_depth, "mm"));
echo(str("Furo               : Ø", edge_hole_d, "mm × ", edge_hole_depth, "mm + rebaixo Ø", recess_d, "mm × ", edge_collar_depth, "mm"));
echo(str("Tolerância         : ", tolerance, "mm"));
echo("---");
echo(str("Posições nas extremidades (= centro da seção): ", edge_inset == sec_w / 2 ? "SIM" : "VERIFICAR (edge_inset != sec_w/2)"));
echo(str("Compatível com furo de borda PLATE/ATOM       : ", edge_pin_len < edge_hole_depth ? "SIM" : "VERIFICAR"));

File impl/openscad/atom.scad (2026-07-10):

// ============================================================
// ATOM — Design System 3D Modular
// ============================================================
// Unidade base do sistema de encaixe modular.
// Cada ATOM é um cubo com furos passantes em todas as 6 faces
// e um baixo relevo ao redor de cada furo.
//
// Parâmetros editáveis:
// - atom_size     : tamanho base de 1 ATOM (mm)
// - qty_x         : quantidade de ATOMs no eixo X
// - qty_y         : quantidade de ATOMs no eixo Y
// - qty_z         : quantidade de ATOMs no eixo Z
// - hole_d        : diâmetro do furo passante (mm)
// - relief_depth  : profundidade do baixo relevo (mm)
// - relief_margin : margem do baixo relevo ao redor do furo (mm)
// - border_radius : raio de arredondamento das arestas (mm)
// ============================================================

/* [Tamanho do ATOM] */

// Tamanho base de 1 ATOM (mm)
atom_size = 20; // [5:1:100]

// Raio de arredondamento das arestas (0 = sem arredondamento)
border_radius = 0; // [0:0.1:5]

// Estilo do acabamento das arestas: round (raio) ou chamfer (chanfro 45°)
border_style = "round"; // [round, chamfer]

/* [Quantidade de ATOMs] */

// Quantidade de ATOMs no eixo X
qty_x = 1; // [1:1:10]

// Quantidade de ATOMs no eixo Y
qty_y = 1; // [1:1:10]

// Quantidade de ATOMs no eixo Z
qty_z = 1; // [1:1:10]

/* [Furos] */

// Diâmetro do furo passante (mm)
hole_d = 10; // [0.5:0.1:15]

// Profundidade do baixo relevo ao redor do furo (mm)
relief_depth = 2; // [0.1:0.05:5]

// Margem do baixo relevo ao redor do furo (mm)
relief_margin = 2; // [0.5:0.1:5]

/* [Furos de borda — interface lateral, compatível com PLATE] */

// Diâmetro dos furos de borda (0 = sem furos de borda)
edge_hole_d = 3; // [0:0.1:5]

// Profundidade dos furos de borda (mm)
edge_hole_depth = 4; // [1:0.5:10]

// Distância do centro do furo até a extremidade (= thickness/2 da PLATE)
edge_inset = 2.5; // [1:0.25:5]

// Rebaixo na boca do furo — recebe o colar do pino (trava de
// profundidade). Largura radial = 1 bico de 0.4mm (0 = sem rebaixo)
edge_collar_w = 0.4; // [0:0.1:1]

// Profundidade do rebaixo do colar (mm)
edge_collar_depth = 1; // [0.5:0.25:2]

/* [Qualidade] */

// Segmentos dos cilindros e esferas (mais = mais suave, mais lento)
$fn = 32;

// ============================================================
// CALCULADOS
// ============================================================

// Diâmetro total do baixo relevo
relief_d = hole_d + (relief_margin * 2);

// Raio seguro — não pode ser maior que metade do atom_size
safe_radius = min(border_radius, atom_size / 2 - 0.01);

// ============================================================
// MÓDULOS
// ============================================================

// ------------------------------------------------------------
// Módulo: sólido de acabamento das arestas — esfera (round)
// ou octaedro (chamfer 45°), usado no minkowski
// ------------------------------------------------------------
module border_finish(r) {
    if (border_style == "chamfer")
        polyhedron(
            points = [[r,0,0],[-r,0,0],[0,r,0],[0,-r,0],[0,0,r],[0,0,-r]],
            faces  = [[4,2,0],[4,1,2],[4,3,1],[4,0,3],[5,0,2],[5,2,1],[5,1,3],[5,3,0]]
        );
    else
        sphere(r = r);
}

// ------------------------------------------------------------
// Módulo: cubo com acabamento de aresta via minkowski
// Quando border_radius = 0, usa cubo simples (mais rápido)
// ------------------------------------------------------------
module rounded_cube(size, r) {
    if (r <= 0) {
        cube([size, size, size], center = true);
    } else {
        // Minkowski de um cubo menor + sólido de acabamento
        // O cubo interno é reduzido em 2*r para manter o tamanho externo
        inner = size - 2 * r;
        minkowski() {
            cube([inner, inner, inner], center = true);
            border_finish(r);
        }
    }
}

// ------------------------------------------------------------
// Módulo: um único ATOM centrado na origem
// ------------------------------------------------------------
module atom_unit() {
    difference() {
        // Corpo principal (com ou sem border radius)
        rounded_cube(atom_size, safe_radius);

        // ---- EIXO Z — furo passante (topo → base) ----
        cylinder(d = hole_d, h = atom_size + 1, center = true);

        // Baixo relevo face TOPO (+Z)
        translate([0, 0, atom_size / 2 - relief_depth])
            cylinder(d = relief_d, h = relief_depth + 0.01);

        // Baixo relevo face BASE (-Z)
        translate([0, 0, -atom_size / 2])
            cylinder(d = relief_d, h = relief_depth + 0.01);

        // ---- EIXO X — furo passante (direita → esquerda) ----
        rotate([0, 90, 0])
            cylinder(d = hole_d, h = atom_size + 1, center = true);

        // Baixo relevo face +X
        translate([atom_size / 2 - relief_depth, 0, 0])
            rotate([0, 90, 0])
                cylinder(d = relief_d, h = relief_depth + 0.01);

        // Baixo relevo face -X
        translate([-atom_size / 2, 0, 0])
            rotate([0, 90, 0])
                cylinder(d = relief_d, h = relief_depth + 0.01);

        // ---- EIXO Y — furo passante (frente → trás) ----
        rotate([90, 0, 0])
            cylinder(d = hole_d, h = atom_size + 1, center = true);

        // Baixo relevo face +Y
        translate([0, atom_size / 2, 0])
            rotate([90, 0, 0])
                cylinder(d = relief_d, h = relief_depth + 0.01);

        // Baixo relevo face -Y
        translate([0, -atom_size / 2, 0])
            rotate([-90, 0, 0])
                cylinder(d = relief_d, h = relief_depth + 0.01);
    }
}

// ------------------------------------------------------------
// Módulo: grid de ATOMs — qty_x * qty_y * qty_z
// ------------------------------------------------------------
module atom_grid() {
    for (ix = [0 : qty_x - 1])
        for (iy = [0 : qty_y - 1])
            for (iz = [0 : qty_z - 1])
                translate([
                    ix * atom_size + atom_size / 2,
                    iy * atom_size + atom_size / 2,
                    iz * atom_size + atom_size / 2
                ])
                atom_unit();
}

// ------------------------------------------------------------
// Módulo: furos de borda — 4 por face lateral (2 embaixo + 2
// em cima por célula), nas extremidades: edge_inset das bordas.
// Compatível com os furos de borda da PLATE — uma PLATE ao lado
// de um ATOM conecta via BRIDGE, respeitando o grid.
// Aplicados só nas 4 faces laterais EXTERNAS do grid.
// ------------------------------------------------------------
// Furo de borda: bore Ø3 + rebaixo do colar na boca
module atom_edge_hole_cut() {
    eps = 0.01;
    cylinder(d = edge_hole_d, h = edge_hole_depth + eps);
    if (edge_collar_w > 0)
        cylinder(d = edge_hole_d + 2 * edge_collar_w, h = edge_collar_depth + eps);
}

module atom_edge_holes() {
    eps = 0.01;
    total_x = qty_x * atom_size;
    total_y = qty_y * atom_size;

    // Posições ao longo da largura (por célula) e alturas (por camada)
    xs = [ for (c = [0 : qty_x - 1], s = [0, 1]) c * atom_size + edge_inset + s * (atom_size - 2 * edge_inset) ];
    ys = [ for (c = [0 : qty_y - 1], s = [0, 1]) c * atom_size + edge_inset + s * (atom_size - 2 * edge_inset) ];
    zs = [ for (c = [0 : qty_z - 1], s = [0, 1]) c * atom_size + edge_inset + s * (atom_size - 2 * edge_inset) ];

    for (z = zs) {
        // Faces +Y / -Y (furos ao longo de X)
        for (x = xs) {
            translate([x, total_y + eps, z])
                rotate([90, 0, 0])
                    atom_edge_hole_cut();
            translate([x, -eps, z])
                rotate([-90, 0, 0])
                    atom_edge_hole_cut();
        }
        // Faces +X / -X (furos ao longo de Y)
        for (y = ys) {
            translate([total_x + eps, y, z])
                rotate([0, -90, 0])
                    atom_edge_hole_cut();
            translate([-eps, y, z])
                rotate([0, 90, 0])
                    atom_edge_hole_cut();
        }
    }
}

// ------------------------------------------------------------
// Módulo: ATOM completo — grid + interface de borda
// ------------------------------------------------------------
module atom() {
    difference() {
        atom_grid();
        if (edge_hole_d > 0)
            atom_edge_holes();
    }
}

// ============================================================
// RENDER
// ============================================================
part_color = [0.35, 0.38, 0.42];
color(part_color) atom();
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

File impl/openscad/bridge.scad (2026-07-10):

// ============================================================
// BRIDGE — Design System 3D Modular
// ============================================================
// Dowel de junção coplanar: pino duplo que atravessa a junção
// entre duas PLATEs (ou PLATE↔ATOM) encostadas borda a borda,
// entrando nos furos de borda de cada lado.
//
// Vista de cima (junção vertical no centro):
//
//   PLATE A      │      PLATE B
//        ━━━━━━━━┿━━━━━━━━      ← dowel Ø2.8 (metade em cada furo)
//                │ ← peças ENCOSTADAS — gap zero
//
// Junção 100% invisível: nenhum furo de face consumido, nada
// acima ou abaixo da superfície. Usar 2 dowels por junção
// (um em cada furo de borda do par de células) para travar
// rotação.
//
// Sem canal de fio: a seção Ø2.8 não comporta canal — fios
// atravessam a junção pelos furos de face, que ficam livres.
//
// Parâmetros:
// - edge_hole_d     : furo de borda da PLATE/ATOM (igual às peças)
// - edge_hole_depth : profundidade do furo de borda
// - tolerance       : folga de encaixe
// ============================================================

/* [Interface de borda — manter igual à PLATE/ATOM] */

// Diâmetro do furo de borda (mm)
edge_hole_d = 3; // [1:0.1:5]

// Profundidade do furo de borda (mm)
edge_hole_depth = 4; // [1:0.5:10]

// Rebaixo do colar na boca dos furos (manter igual à PLATE/ATOM)
// Colar central no dowel: trava de profundidade — divide 50/50
edge_collar_w = 0.4; // [0:0.1:1]

// Profundidade do rebaixo / meia-altura do colar (mm)
edge_collar_depth = 1; // [0.5:0.25:2]

/* [Tolerância de impressão] */

// Folga de encaixe — reduz o pino para caber no furo de borda
tolerance = 0.2; // [0:0.05:0.5]

/* [Qualidade] */
$fn = 32;

// ============================================================
// CALCULADOS
// ============================================================

// Diâmetro efetivo do pino (com tolerância)
pin_d = edge_hole_d - tolerance;

// Diâmetro do colar central (assenta nos rebaixos das duas bocas)
collar_d = edge_hole_d + 2 * edge_collar_w - tolerance;

// Meio-comprimento em cada furo — menor que a profundidade
// do furo para não bater no fundo
pin_half_len = edge_hole_depth - 0.5;

// Comprimento total do dowel
pin_len = pin_half_len * 2;

// ============================================================
// MÓDULOS
// ============================================================

// ------------------------------------------------------------
// Módulo: BRIDGE — dowel centrado na origem, eixo X
// (junção fica no plano X = 0)
// ------------------------------------------------------------
module bridge() {
    // Corpo do dowel
    translate([-pin_half_len, 0, 0])
        rotate([0, 90, 0])
            cylinder(d = pin_d, h = pin_len);

    // Colar central — 1 edge_collar_depth para cada lado da junção,
    // assenta nos rebaixos das bocas dos dois furos
    if (edge_collar_w > 0)
        translate([-edge_collar_depth, 0, 0])
            rotate([0, 90, 0])
                cylinder(d = collar_d, h = edge_collar_depth * 2);
}

// ============================================================
// RENDER
// ============================================================
part_color = [0.35, 0.38, 0.42];
color(part_color) bridge();

// ============================================================
// INFO — dimensões no console
// ============================================================
echo("=== BRIDGE ===");
echo(str("Dowel              : Ø", pin_d, "mm × ", pin_len, "mm (", pin_half_len, "mm em cada peça)"));
echo(str("Colar central      : ", edge_collar_w > 0 ? str("Ø", collar_d, "mm × ", edge_collar_depth * 2, "mm (trava 50/50)") : "sem colar"));
echo(str("Tolerância         : ", tolerance, "mm"));
echo("Uso                : 2 dowels por junção (um por furo de borda do par de células)");
echo("---");
echo(str("Pino cabe no furo (prof. ", edge_hole_depth, "mm): ", pin_half_len < edge_hole_depth ? "SIM" : "VERIFICAR"));

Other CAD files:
impl/openscad/corner.scad
examples/rover-chassis/assembly.scad
examples/u-channel/assembly.scad
impl/openscad/elbow.scad
impl/openscad/link.scad
impl/openscad/plate.scad
impl/openscad/vertex.scad

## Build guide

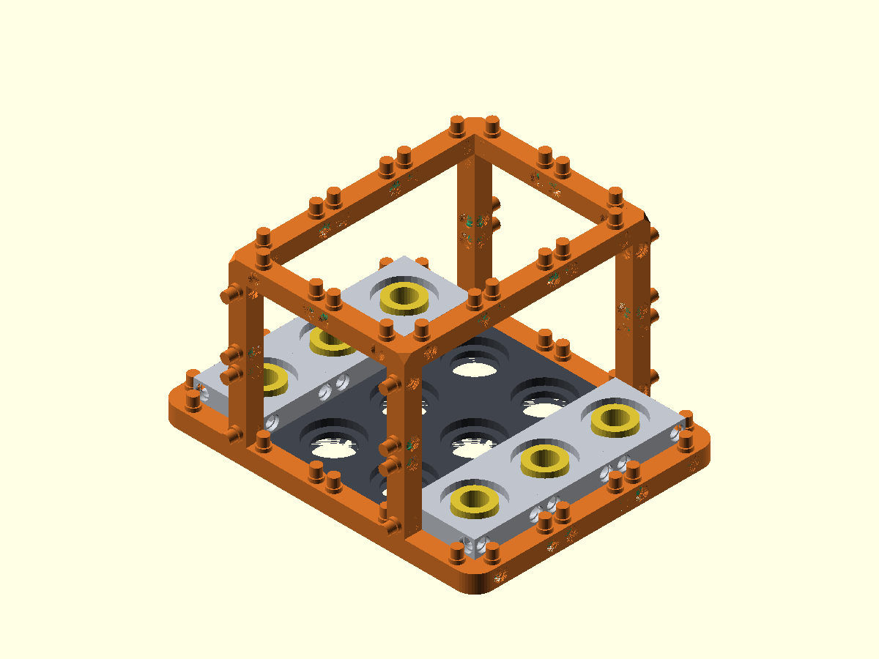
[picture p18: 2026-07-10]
examples/rover-chassis/assembly.png

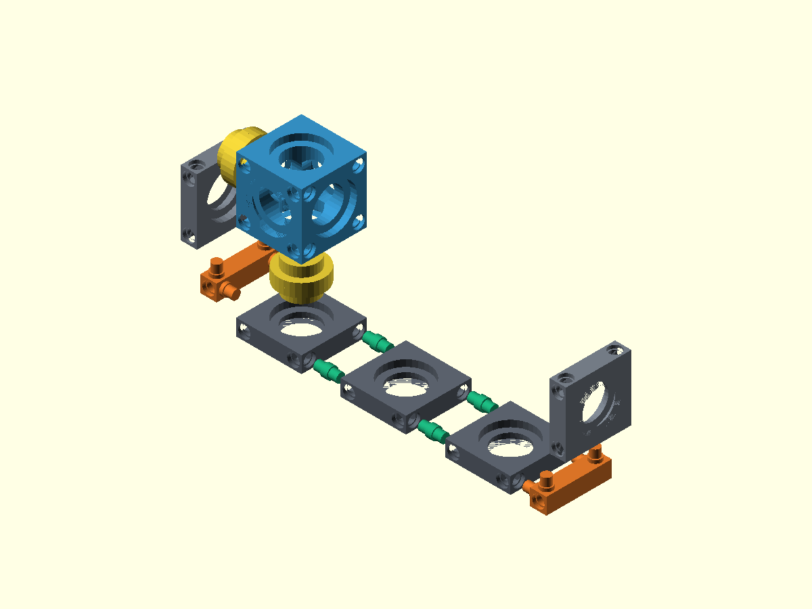
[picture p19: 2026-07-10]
examples/u-channel/assembly-exploded.png

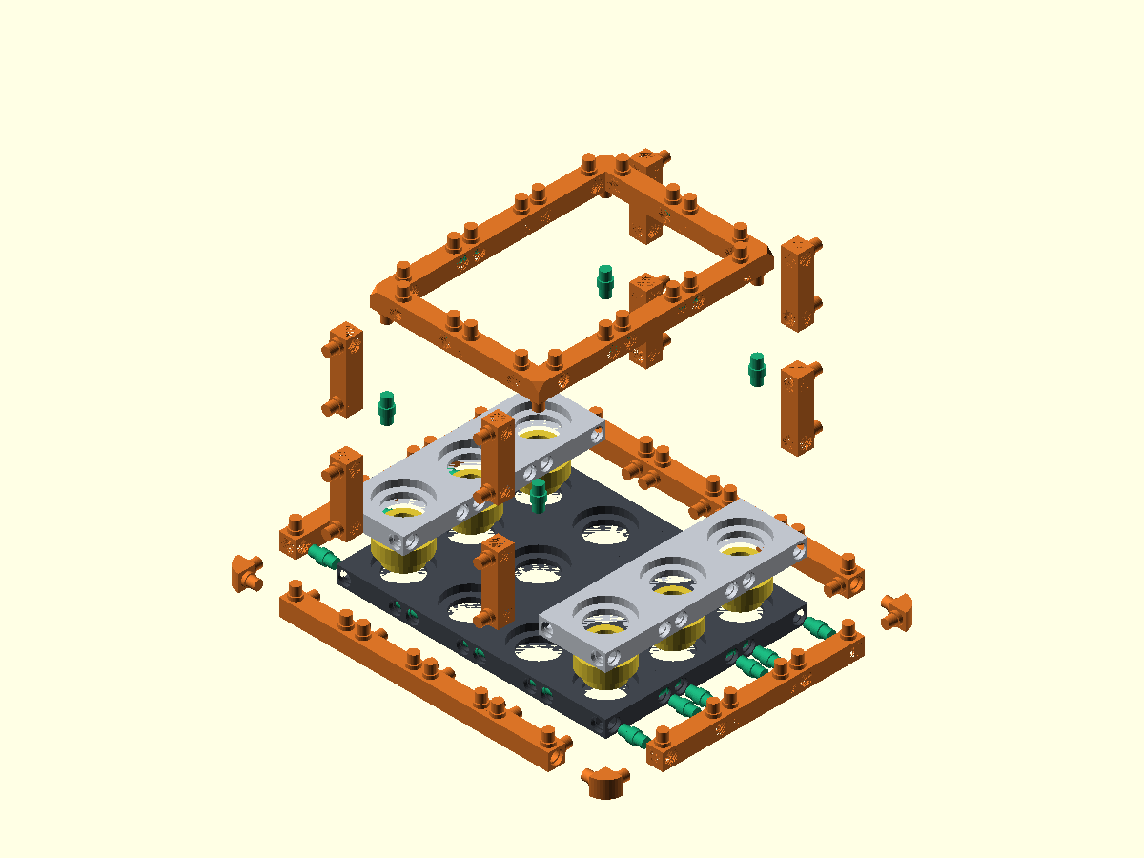
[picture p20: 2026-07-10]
examples/rover-chassis/assembly-exploded.png

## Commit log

2026-07-05 feat: adiciona implementação das especificações, adiciona hack/automations para automações de geração de renders utilizando o openscad
    [atom.scad, link.scad, plate.scad]
2026-07-05 fix: plate implementation
    [plate.scad]
2026-07-05 refactor: melhora a automação do openscad para geração, cores, comandos de preview e build, leitura dinâmica da pasta de parts da implementação
2026-07-05 refactor: melhora implementação das cores, repassa cor via parâmetro para o openscad via -D, adiciona componentes em tabela no README.md
    [atom.scad, link.scad, plate.scad]
2026-07-05 fix: ajuste parâmetros default e preview
    [atom.scad]
2026-07-08 feat: v0.2.0 — interface de borda, junções invisíveis e Lei do Grid
    [assembly copy.scad, assembly.scad, atom.stl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]
2026-07-08 feat: adiciona automações para gerar animações de peças e montagem, atualiza readme e documentação
    [assembly copy.scad]
2026-07-08 feat: gera novos modelos stl
    [atom.stl, bridge.stl, corner.stl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]
2026-07-08 feat: add ffmpeg como dependência, adiciona automação para geração de assembly em binário mp4, ajusta readme
2026-07-10 feat: improve project engineering, add new parts, improve automation, add new assembly, add agent skil for make assemblies with parts, update README, update previews and stls
    [assembly.scad, atom.scad, atom.stl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]

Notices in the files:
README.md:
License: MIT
